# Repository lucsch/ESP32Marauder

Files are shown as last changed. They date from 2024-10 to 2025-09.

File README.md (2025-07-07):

<!---[![License: MIT](https://img.shields.io/github/license/mashape/apistatus.svg)](https://github.com/justcallmekoko/ESP32Marauder/blob/master/LICENSE)--->
<!---[![Gitter](https://badges.gitter.im/justcallmekoko/ESP32Marauder.png)](https://gitter.im/justcallmekoko/ESP32Marauder)--->
<!---[![Build Status](https://travis-ci.com/justcallmekoko/ESP32Marauder.svg?branch=master)](https://travis-ci.com/justcallmekoko/ESP32Marauder)--->
<!---Shields/Badges https://shields.io/--->

# ESP32 Marauder
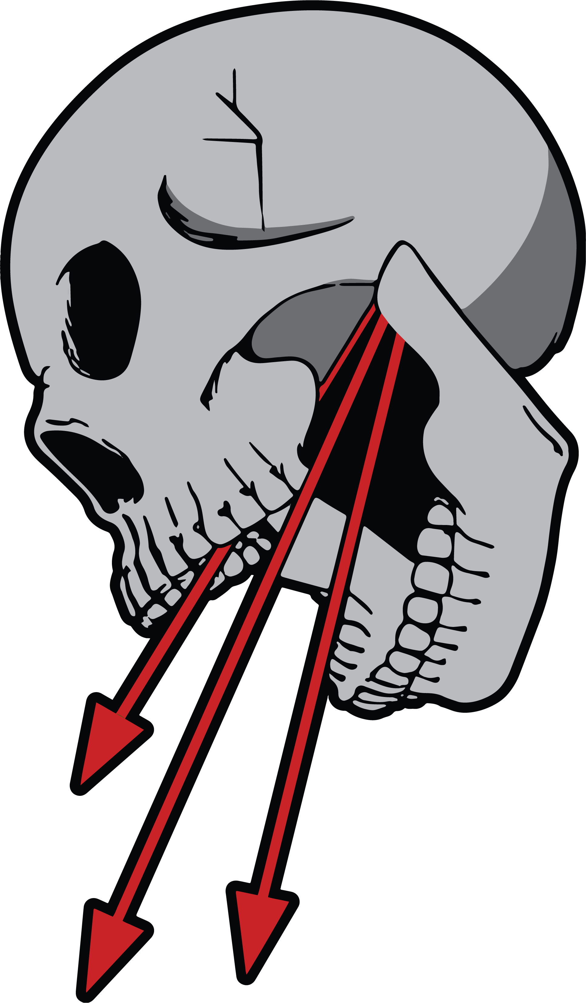
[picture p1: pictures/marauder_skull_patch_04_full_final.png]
Marauder logo

<p align="center">
  <b>A suite of WiFi/Bluetooth offensive and defensive tools for the ESP32</b>
  <br><br>
  
  
  
  <br>
  
  
  <br><br>
</p>
    


## Getting Started
Download the [latest release](https://github.com/justcallmekoko/ESP32Marauder/releases/latest) of the firmware.  

Check out the project [wiki](https://github.com/justcallmekoko/ESP32Marauder/wiki) for a full overview of the ESP32 Marauder

# For Sale Now
You can buy the ESP32 Marauder using [this link](https://www.justcallmekokollc.com)

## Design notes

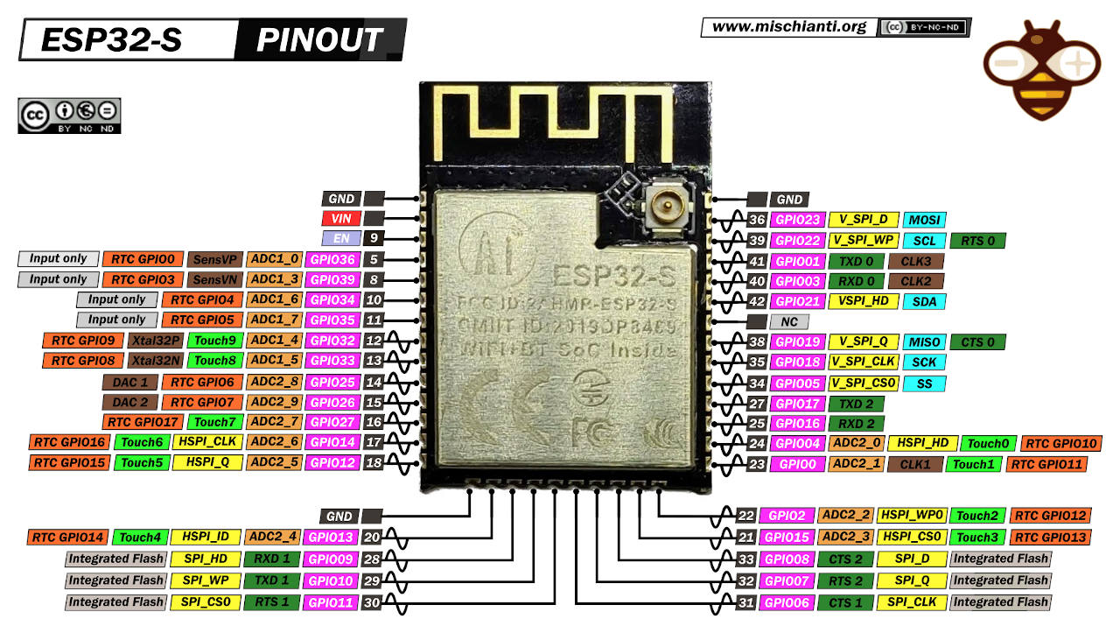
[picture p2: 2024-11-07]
schematics/esp32v6/documents/ESP32-S-pinout-mischianti-low-resolution.jpg

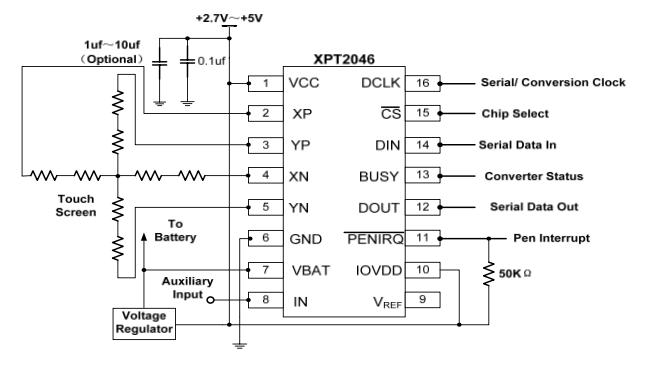
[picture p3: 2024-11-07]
schematics/esp32v6/documents/xpt2046.png

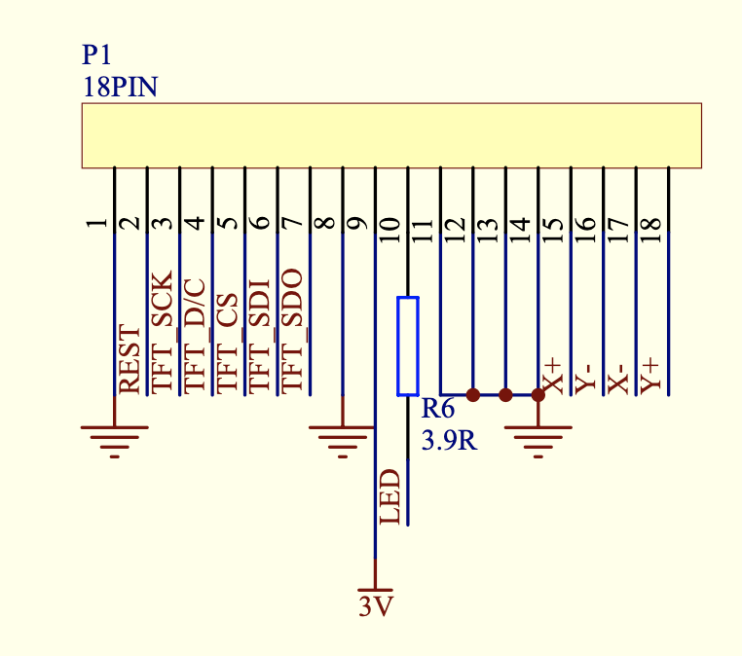
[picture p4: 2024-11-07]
schematics/esp32v6/documents/ili9341.png

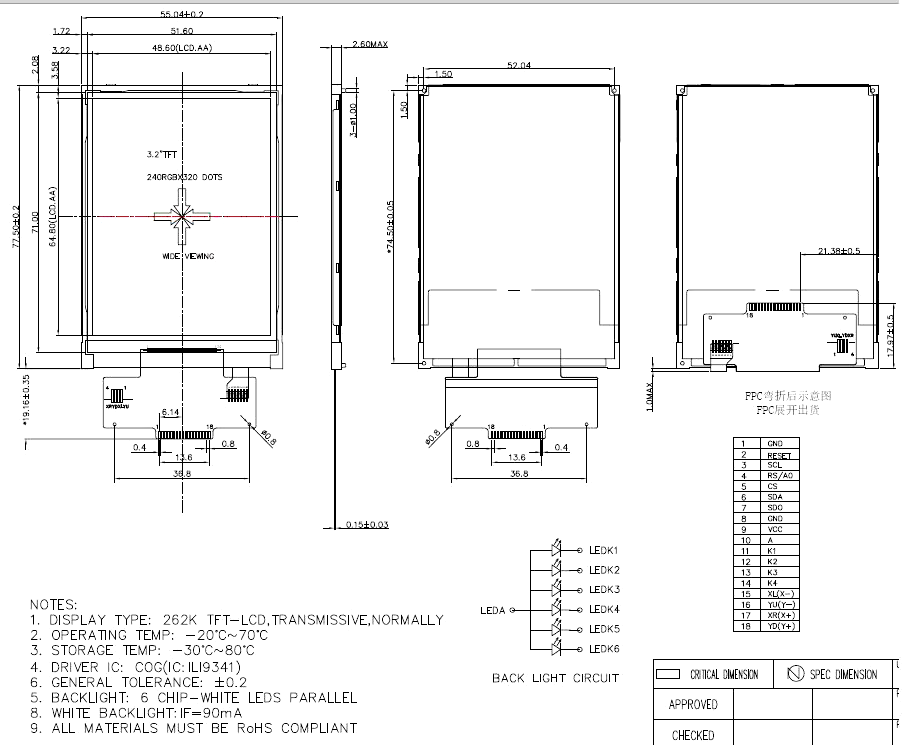
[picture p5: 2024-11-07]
schematics/esp32v6/documents/tft_display_datasheet.png

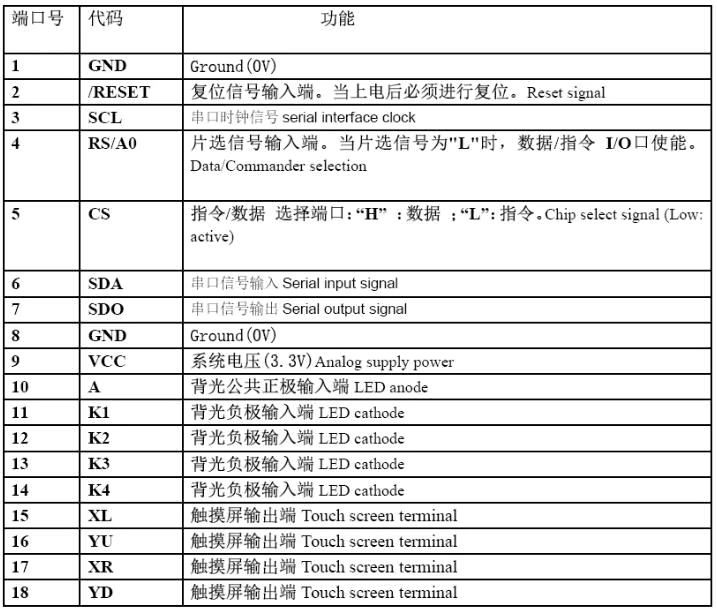
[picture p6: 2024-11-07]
schematics/esp32v6/documents/tft_display_datasheet2.png

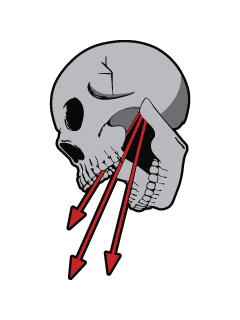
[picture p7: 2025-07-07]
pictures/marauder_skull_240x320-01-01.png

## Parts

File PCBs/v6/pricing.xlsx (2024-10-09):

null | References | Value | Footprint | Quantity | Remarque | Prix
1 | C4, C5, C6, C7, C9, C11 | 22uF | 805 | 6
2 | C1, C8, C10 | 10uF | 805 | 3
3 | C2, C3 | 100nF | 805 | 2
4 | C12 | 100nF | C0603 | 1
5 | R2, R4, R5, R6, R8, R10 | 10KΩ | 603 | 6
6 | R14, R16, R17, R18 | 1K | R0603 | 4
7 | R1, R3 | 470Ω | 805 | 2
8 | R11, R12 | 2.2K | R0603 | 2
9 | R7 | 2 | 603 | 1 |  | 0.0363
10 | R9 | 0.5 | 603 | 1 |  | 0.0398
11 | R13 | 10K | R0603 | 1
12 | R15 | 10 | R0603 | 1
13 | R19 | 330 | R0603 | 1
14 | L1 | 1uH | L-SMD-5.4X5.1 | 1 | Inductance | 0.175
15 | U1 | CH340C | SOP-16_150MIL | 1 | USB2Serial | 0.778
16 | U2 | AMS1117-3.3 | SOT-223 | 1 | LDO | 0.0188
17 | U3 | ESP-32S | ESP-32S | 1 | MCU | 1.99
18 | U5 | IP5306 | ESOP-8-EP | 1 | Power Management | 0.71
19 | U6 | XPT2046 | TSSOP-16_L5.0-W4.4-P0.65-LS6.4-BL | 1 | Contrôleur écran | 0.18
20 | U7 | ILI9341_18_PIN | ILI9341 18 PIN | 1 | Ecran | 4.79
21 | U8 | 1042P | KEYSTONE 18650 BATTERY SLED | 1 | support batterie | 0.88
22 | SW1 | POWER | KEY-TACT-SMD-7.6*3.5*3.5 | 1 | bouton latéral | 0.1016
23 | Q1, Q2 | S8050 | SOT-23(SOT-23-3) | 2 | transistor | 0.0152
24 | CARD1 | TF-115 | TF-SMD_TF-115 | 1
25 | FLASH1 | FLASH | KEY-5.2X5.2X1.5 | 1 | bouton flash | 0.0266
26 | LED1 | WS2812B-B | LED-SMD_4P-L5.0-W5.0-BL | 1
27 | Q3 | S8050_C402279 | SOT-23-3_L3.0-W1.7-P0.95-LS2.9-BR | 1 | transistor | 0.0152
28 | RESET1 | RESET | KEY-5.2X5.2X1.5 | 1 | bouton reset | 0.0266
29 | USB1 | MICROXNJ | MICRO-USB-SMD_MICROXNJ | 1
30 | P1 | Header-Female-2.54_1x16 | HDR-16X1/2.54 | 1
 |  |  |  |  | Batterie 18650 | 1.531666667
 |  |  |  |  | antenne wifi | 0.599
 |  |  |  |  | GPS | 2.43
 |  |  |  |  | PCB | 3.488

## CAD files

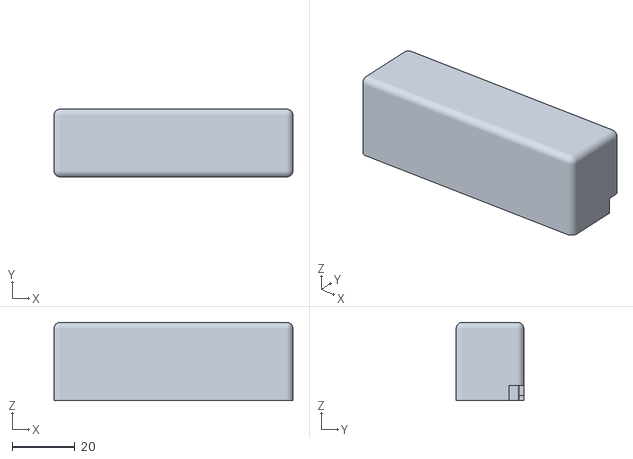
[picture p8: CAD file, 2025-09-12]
mechanical/C5 Adapter/c5 adapter pin cover.stl
76.2 x 21.6 x 25.0

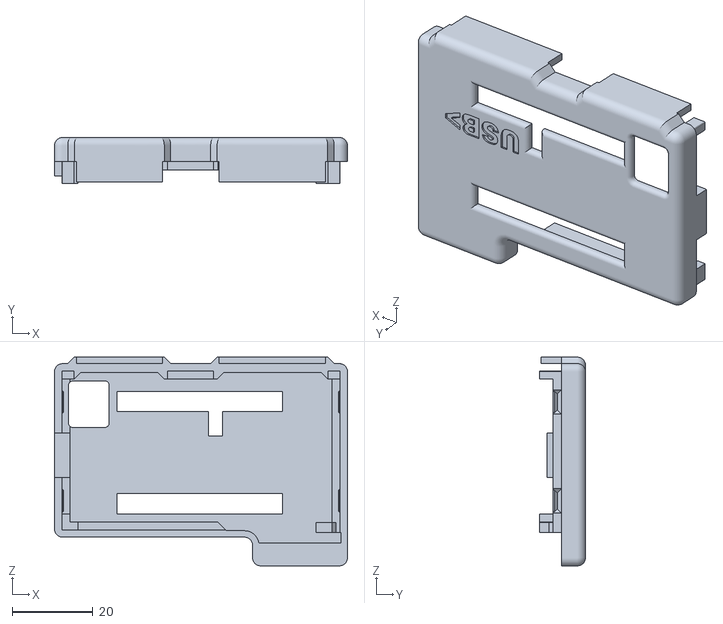
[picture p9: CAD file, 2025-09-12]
mechanical/C5 Adapter/Extra designs/c5 adapter front - SMA.stl
72.6 x 11.4 x 51.7

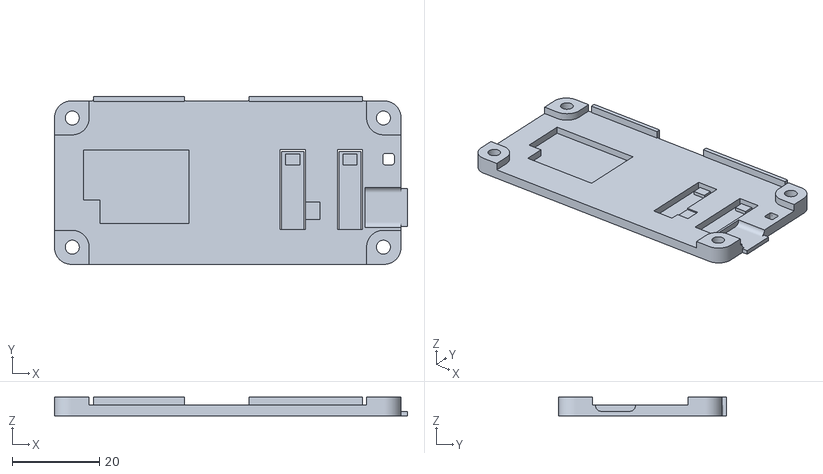
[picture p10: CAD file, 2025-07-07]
mechanical/Flipper Zero WiFi Dev Board/FlipperZero Dev Board Enclosure JCMK Lid.stl
80.7 x 38.3 x 4.30

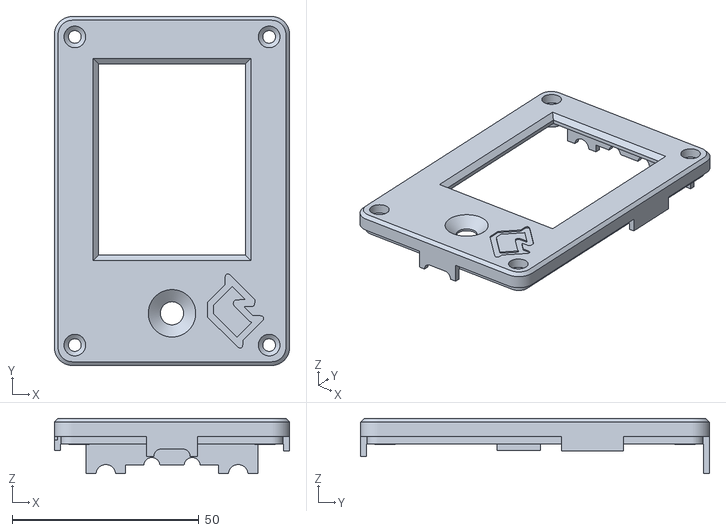
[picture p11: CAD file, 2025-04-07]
mechanical/V7/Front.stl
63.0 x 93.5 x 14.8

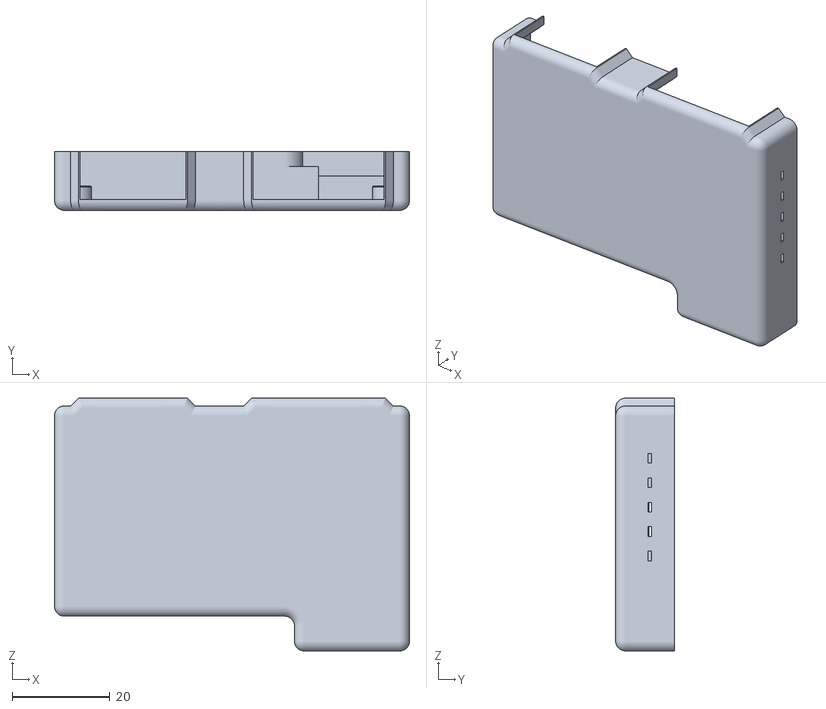
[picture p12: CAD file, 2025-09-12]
mechanical/C5 Adapter/c5 adapter back.stl
72.6 x 12.0 x 51.7

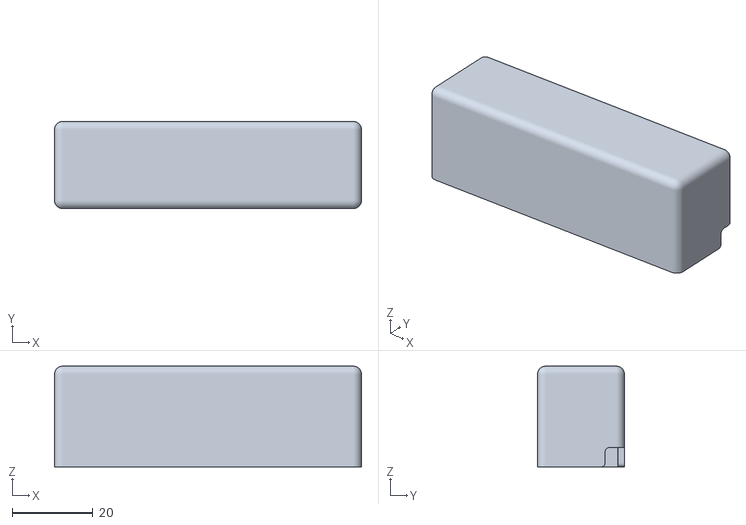
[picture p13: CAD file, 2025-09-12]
mechanical/C5 Adapter/Extra designs/c5 adapter pin cover - with cut out.stl
76.2 x 21.6 x 25.0

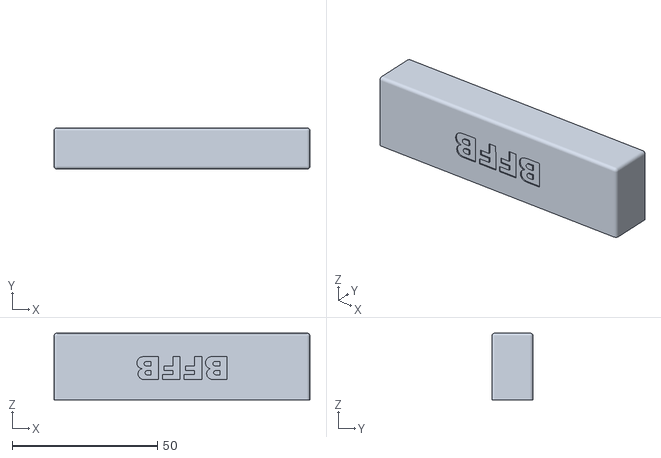
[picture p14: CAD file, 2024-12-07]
mechanical/Flipper Zero BFFB/Enclosure/GPIO Cover.stl
88.1 x 14.2 x 23.0

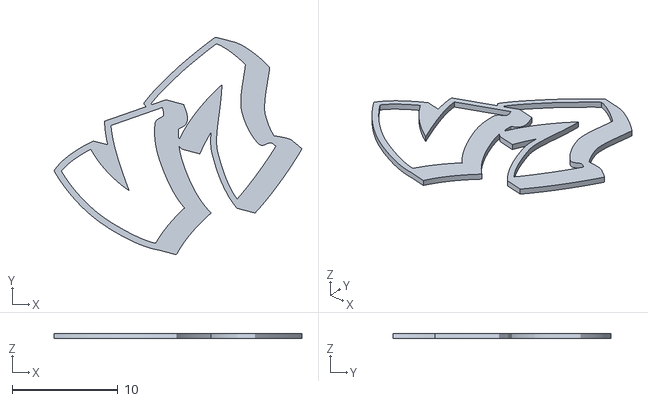
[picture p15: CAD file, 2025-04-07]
mechanical/V7/Inlay/v7 Outline.stl
23.4 x 20.6 x 0.5

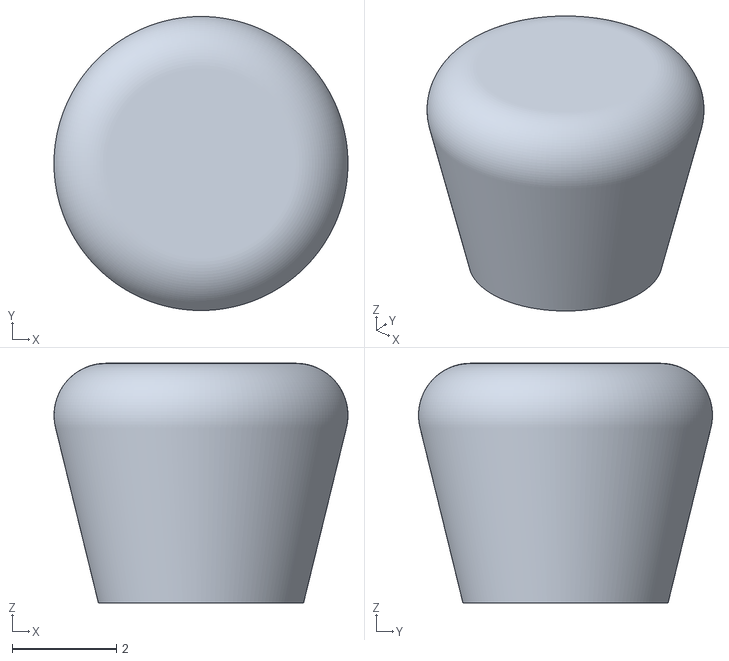
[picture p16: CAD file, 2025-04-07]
mechanical/V7/Joystick.stl
5.65 x 5.65 x 4.60

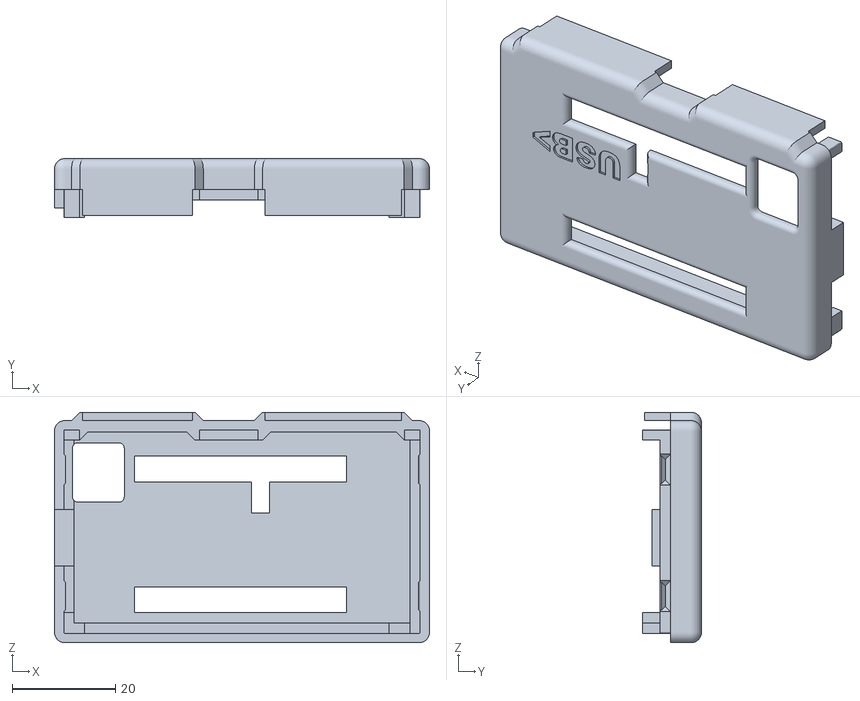
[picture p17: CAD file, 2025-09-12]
mechanical/C5 Adapter/Extra designs/c5 adapter front - logo cut out.stl
72.6 x 11.4 x 44.6

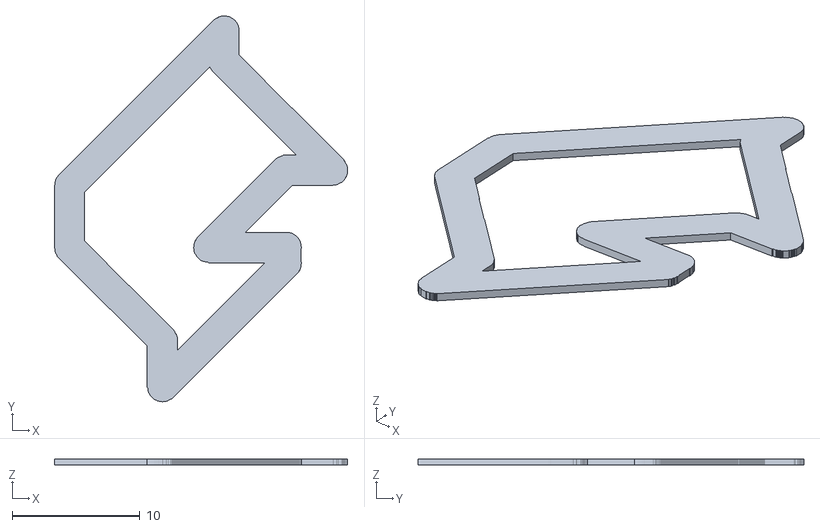
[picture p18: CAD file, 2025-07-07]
mechanical/Flipper Zero WiFi Dev Board/FlipperZero Dev Board Enclosure JCMK Inlay.stl
23.0 x 30.2 x 0.5

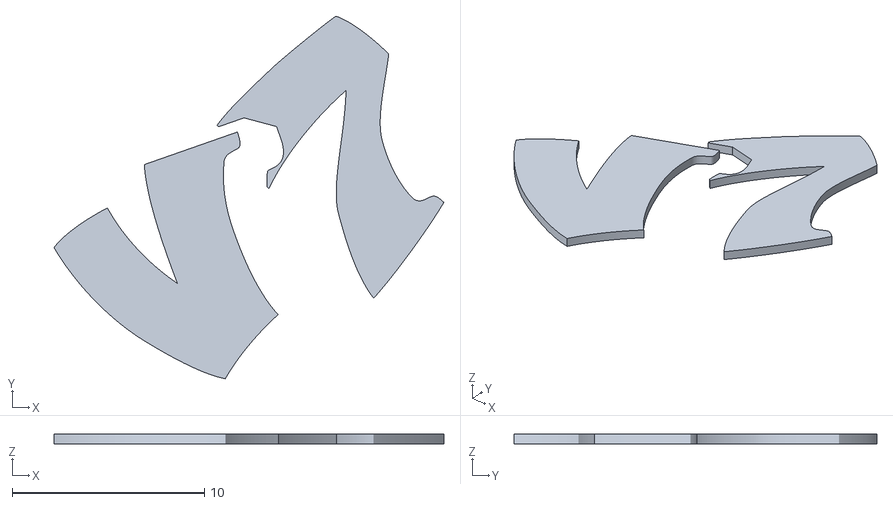
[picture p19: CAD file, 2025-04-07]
mechanical/V7/Inlay/v7 Fill.stl
20.3 x 18.8 x 0.5

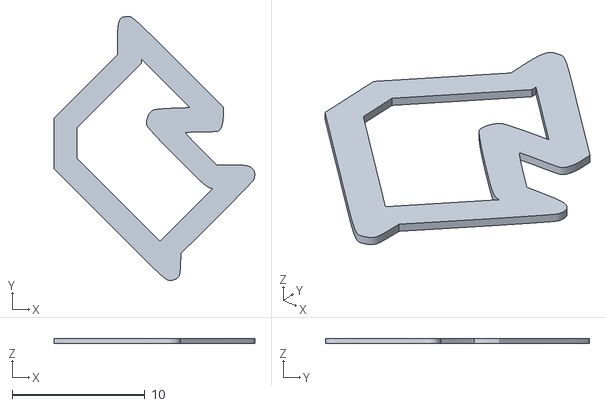
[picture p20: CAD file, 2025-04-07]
mechanical/V7/JCMK Inlay.stl
15.1 x 19.9 x 0.4

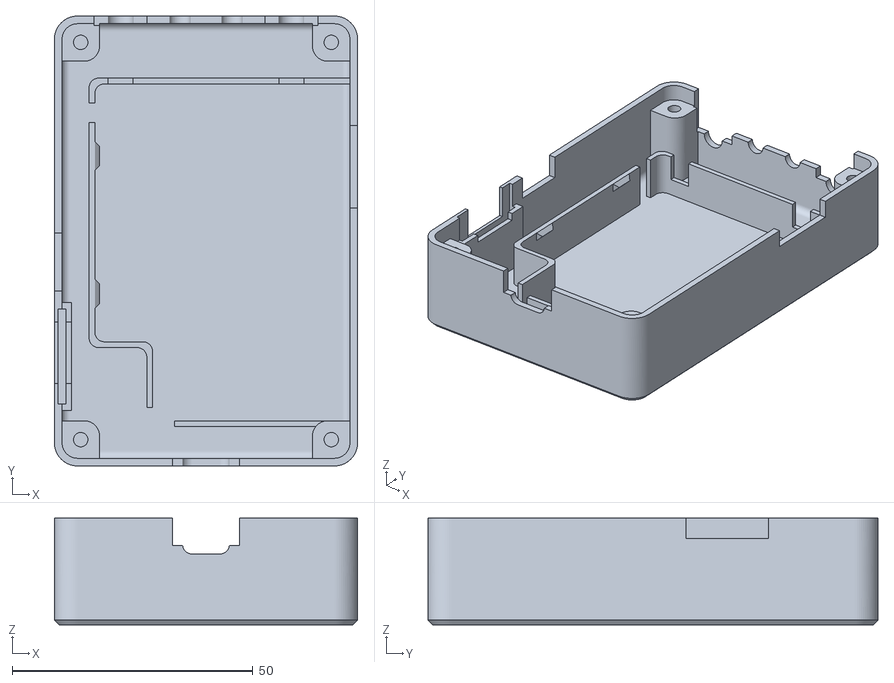
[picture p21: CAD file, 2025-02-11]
mechanical/V7/Back.stl
63.0 x 93.5 x 22.2

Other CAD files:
mechanical/V7/Inlay/Front_debos.stl
mechanical/C5 Adapter/c5 adapter front.stl
mechanical/C5 Adapter/Extra designs/c5 adapter pin cover - cut out with JCMK x AWOK logos.stl
mechanical/C5 Adapter/Extra designs/c5 adapter back - SMA.stl
mechanical/C5 Adapter/Extra designs/c5 adapter back - hatched 1.stl
mechanical/C5 Adapter/Extra designs/c5 adapter back - hatched 2.stl
mechanical/C5 Adapter/Extra designs/c5 adapter pin cover - JCMK x AWOK.stl
mechanical/Flipper Zero BFFB/Enclosure/Back.stl
mechanical/Flipper Zero BFFB/Enclosure/Front.stl
mechanical/Flipper Zero WiFi Dev Board/Wifi_Dev_REAR_THRUBOLT_STD_GPS_ANT.stl
mechanical/V6/M6_BOTTOM_LSC.FCStd
mechanical/V6/M6_BOTTOM_LSC.step
mechanical/V6/M6_BOTTOM_LSC_NO_GPS.step
mechanical/V6/MARAUDER_V6_ANTENNA_SUPPORT.step
mechanical/V6/MARAUDER_V6_TOP_LOGO_BSI.FCStd
mechanical/V6/cnc/boite_couvercle.dxf
mechanical/V6/cnc/lipo_pad.dxf
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

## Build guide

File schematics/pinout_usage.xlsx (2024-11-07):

PIN | ECRAN (ILI9341) | TACTILE (XPT2046) | SDCARD (TF-115) | PIN_HEADER | NOT_USED | MISC | Remarque
EN-RESET |  |  |  | 1
GPIO36 |  |  |  | 1
GPIO39 |  |  |  | 1
GPIO34 |  |  |  | 1
GPIO35 |  |  |  | 1
GPIO32 | Pilote Transistor |  |  |  |  |  | pilote transistor
GPIO33 |  |  |  |  |  | Mesure LED2
GPIO25 |  |  |  |  |  | Neopixel LED
GPIO26 |  |  |  |  | 1
GPIO27 |  |  |  |  | 1
GPIO14 |  |  |  | 1
GPIO12 |  |  | SPI_CS | 1
GPIO13 |  |  |  | 1
GPIO15 |  |  |  |  |  |  | Pull down uniquement
GPIO02 |  |  |  | 1
GPIO00 |  |  |  | 1 |  |  | Circuit Flash
GPIO04 |  |  |  | 1
GPIO16 | TFT_DC
GPIO17 | TFT_CS
GPIO05 | REST
GPIO18 | TFT_SCK | CLK | SPI_CLK |  |  |  | Clock
GPIO19 |  | DOUT | SPI_MISO
GPIO21 |  | CS
GPIO03 |  |  |  | 1 |  |  | RXD
GPIO01 |  |  |  | 1 |  |  | TXD
GPIO22 |  |  |  |  |  | Mesure LED1
GPIO23 | TFT_SDI-SDO | DIN | SPI_MOSI

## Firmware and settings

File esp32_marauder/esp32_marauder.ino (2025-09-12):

/* FLASH SETTINGS
Board: LOLIN D32
Flash Frequency: 80MHz
Partition Scheme: Minimal SPIFFS
https://www.online-utility.org/image/convert/to/XBM
*/

#include "configs.h"

#ifndef HAS_SCREEN
  #define MenuFunctions_h
  #define Display_h
#endif

#include <WiFi.h>
#include "EvilPortal.h"
#include <Wire.h>
#include "esp_wifi.h"
#include "esp_wifi_types.h"
#include <stdio.h>
#include "freertos/FreeRTOS.h"
#include "freertos/task.h"
#include "esp_system.h"
#include <Arduino.h>

#ifdef HAS_GPS
  #include "GpsInterface.h"
#endif

#include "Assets.h"
#include "WiFiScan.h"
#ifdef HAS_SD
  #include "SDInterface.h"
#endif
#include "Buffer.h"

#ifdef HAS_FLIPPER_LED
  #include "flipperLED.h"
#elif defined(XIAO_ESP32_S3)
  #include "xiaoLED.h"
#elif defined(MARAUDER_M5STICKC) || defined(MARAUDER_M5STICKCP2)
  #include "stickcLED.h"
#elif defined(HAS_NEOPIXEL_LED)
  #include "LedInterface.h"
#endif

#include "settings.h"
#include "CommandLine.h"
#include "lang_var.h"

#ifdef HAS_BATTERY
  #include "BatteryInterface.h"
#endif

#ifdef HAS_SCREEN
  #include "Display.h"
  #include "MenuFunctions.h"
#endif

#ifdef HAS_BUTTONS
  #include "Switches.h"
  
  #if (U_BTN >= 0)
    Switches u_btn = Switches(U_BTN, 1000, U_PULL);
  #endif
  #if (D_BTN >= 0)
    Switches d_btn = Switches(D_BTN, 1000, D_PULL);
  #endif
  #if (L_BTN >= 0)
    Switches l_btn = Switches(L_BTN, 1000, L_PULL);
  #endif
  #if (R_BTN >= 0)
    Switches r_btn = Switches(R_BTN, 1000, R_PULL);
  #endif
  #if (C_BTN >= 0)
    Switches c_btn = Switches(C_BTN, 1000, C_PULL);
  #endif

#endif

WiFiScan wifi_scan_obj;
EvilPortal evil_portal_obj;
Buffer buffer_obj;
Settings settings_obj;
CommandLine cli_obj;

#ifdef HAS_GPS
  GpsInterface gps_obj;
#endif

#ifdef HAS_BATTERY
  BatteryInterface battery_obj;
#endif

#ifdef HAS_SCREEN
  Display display_obj;
  MenuFunctions menu_function_obj;
#endif

#if defined(HAS_SD) && !defined(HAS_C5_SD)
  SDInterface sd_obj;
#endif

#ifdef MARAUDER_M5STICKC
  AXP192 axp192_obj;
#endif

#ifdef HAS_FLIPPER_LED
  flipperLED flipper_led;
#elif defined(XIAO_ESP32_S3)
  xiaoLED xiao_led;
#elif defined(MARAUDER_M5STICKC) || defined(MARAUDER_M5STICKCP2)
  stickcLED stickc_led;
#else
  LedInterface led_obj;
#endif

const String PROGMEM version_number = MARAUDER_VERSION;

#ifdef HAS_NEOPIXEL_LED
  Adafruit_NeoPixel strip = Adafruit_NeoPixel(Pixels, PIN, NEO_GRB + NEO_KHZ800);
#endif

uint32_t currentTime  = 0;

void backlightOn() {
  #ifdef HAS_SCREEN
    #ifdef MARAUDER_MINI
      digitalWrite(TFT_BL, LOW);
    #endif
  
    #ifndef MARAUDER_MINI
      digitalWrite(TFT_BL, HIGH);
    #endif
  #endif
}

void backlightOff() {
  #ifdef HAS_SCREEN
    #ifdef MARAUDER_MINI
      digitalWrite(TFT_BL, HIGH);
    #endif
  
    #ifndef MARAUDER_MINI
      digitalWrite(TFT_BL, LOW);
    #endif
  #endif
}

#ifdef HAS_C5_SD
  SPIClass sharedSPI(SPI);
  SDInterface sd_obj = SDInterface(&sharedSPI, SD_CS);
#endif

void setup()
{
  #ifndef HAS_DUAL_BAND
    esp_spiram_init();
  #endif

  #ifdef HAS_C5_SD
    Serial.println("Starting shared SPI for C5 SD configuration...");
    sharedSPI.begin(SD_SCK, SD_MISO, SD_MOSI);
    delay(100);
  #endif

  #ifdef defined(MARAUDER_M5STICKC) && !defined(MARAUDER_M5STICKCP2)
    axp192_obj.begin();
  #endif

  #if defined(MARAUDER_M5STICKCP2) // Prevent StickCP2 from turning off when disconnect USB cable
    pinMode(POWER_HOLD_PIN, OUTPUT);
    digitalWrite(POWER_HOLD_PIN, HIGH);
  #endif
  
  #ifdef HAS_SCREEN
    pinMode(TFT_BL, OUTPUT);
  #endif
  
  backlightOff();
  #if BATTERY_ANALOG_ON == 1
    pinMode(BATTERY_PIN, OUTPUT);
    pinMode(CHARGING_PIN, INPUT);
  #endif
  
  // Preset SPI CS pins to avoid bus conflicts
  #ifdef HAS_SCREEN
    digitalWrite(TFT_CS, HIGH);
  #endif
  
  #if defined(HAS_SD) && !defined(HAS_C5_SD)
    pinMode(SD_CS, OUTPUT);

    delay(10);
  
    digitalWrite(SD_CS, HIGH);

    delay(10);
  #endif

  Serial.begin(115200);

  while(!Serial)
    delay(10);

  Serial.println("ESP-IDF version is: " + String(esp_get_idf_version()));

  #ifdef HAS_PSRAM
    if (psramInit()) {
      Serial.println("PSRAM is correctly initialized");
    } else {
      Serial.println("PSRAM not available");
    }
  #endif

  #ifdef HAS_SCREEN
    display_obj.RunSetup();
    display_obj.tft.setTextColor(TFT_WHITE, TFT_BLACK);
  #endif

  backlightOff();

  #ifdef HAS_SCREEN
    #ifndef MARAUDER_CARDPUTER
      display_obj.tft.drawCentreString("ESP32 Marauder", TFT_WIDTH/2, TFT_HEIGHT * 0.33, 1);
      display_obj.tft.drawCentreString("JustCallMeKoko", TFT_WIDTH/2, TFT_HEIGHT * 0.5, 1);
      display_obj.tft.drawCentreString(display_obj.version_number, TFT_WIDTH/2, TFT_HEIGHT * 0.66, 1);
    #else
      display_obj.tft.drawCentreString("ESP32 Marauder", TFT_HEIGHT/2, TFT_WIDTH * 0.33, 1);
      display_obj.tft.drawCentreString("JustCallMeKoko", TFT_HEIGHT/2, TFT_WIDTH * 0.5, 1);
      display_obj.tft.drawCentreString(display_obj.version_number, TFT_HEIGHT/2, TFT_WIDTH * 0.66, 1);
    #endif
  #endif


  backlightOn(); // Need this

  #ifdef HAS_SCREEN
    //delay(2000);

    // Do some stealth mode stuff
    #ifdef HAS_BUTTONS
      if (c_btn.justPressed()) {
        display_obj.headless_mode = true;

        backlightOff();

        Serial.println("Headless Mode enabled");
      }
    #endif

    //display_obj.clearScreen();
  
    //display_obj.tft.setTextColor(TFT_CYAN, TFT_BLACK);
  
    //display_obj.tft.println(text_table0[0]);
  
    //delay(2000);
  
    //display_obj.tft.println("Marauder " + display_obj.version_number + "\n");
  
    //display_obj.tft.println(text_table0[1]);
  #endif

  settings_obj.begin();

  buffer_obj = Buffer();
  #if defined(HAS_SD)
    // Do some SD stuff
    if(!sd_obj.initSD())
      Serial.println(F("SD Card NOT Supported"));

  #endif

  wifi_scan_obj.RunSetup();

  #ifdef HAS_SCREEN
    display_obj.tft.setTextColor(TFT_GREEN, TFT_BLACK);
    display_obj.tft.drawCentreString("Initializing...", TFT_WIDTH/2, TFT_HEIGHT * 0.82, 1);
  #endif

  evil_portal_obj.setup();

  #ifdef HAS_BATTERY
    battery_obj.RunSetup();
  #endif

  #ifdef HAS_BATTERY
    battery_obj.battery_level = battery_obj.getBatteryLevel();
  #endif

  // Do some LED stuff
  #ifdef HAS_FLIPPER_LED
    flipper_led.RunSetup();
  #elif defined(XIAO_ESP32_S3)
    xiao_led.RunSetup();
  #elif defined(MARAUDER_M5STICKC)
    stickc_led.RunSetup();
  #else
    led_obj.RunSetup();
  #endif

  #ifdef HAS_GPS
    gps_obj.begin();
  #endif

  #ifdef HAS_SCREEN  
    display_obj.tft.setTextColor(TFT_WHITE, TFT_BLACK);
  #endif

  #ifdef HAS_SCREEN
    menu_function_obj.RunSetup();
  #endif

  wifi_scan_obj.StartScan(WIFI_SCAN_OFF);
  
  Serial.println(F("CLI Ready"));
  cli_obj.RunSetup();
}


void loop()
{
  currentTime = millis();
  bool mini = false;

  #ifdef SCREEN_BUFFER
    #ifndef HAS_ILI9341
      mini = true;
    #endif
  #endif

  #if (defined(HAS_ILI9341) && !defined(MARAUDER_CYD_2USB))
    #ifdef HAS_BUTTONS
      if (c_btn.isHeld()) {
        if (menu_function_obj.disable_touch)
          menu_function_obj.disable_touch = false;
        else
          menu_function_obj.disable_touch = true;

        menu_function_obj.updateStatusBar();

        while (!c_btn.justReleased())
          delay(1);
      }
    #endif
  #endif

  // Update all of our objects
  cli_obj.main(currentTime);
  #ifdef HAS_SCREEN
    display_obj.main(wifi_scan_obj.currentScanMode);
  #endif
  wifi_scan_obj.main(currentTime);

  #ifdef HAS_GPS
    gps_obj.main();
  #endif
  
  // Detect SD card
  #if defined(HAS_SD)
    sd_obj.main();
  #endif

  // Save buffer to SD and/or serial
  buffer_obj.save();

  #ifdef HAS_BATTERY
    battery_obj.main(currentTime);
  #endif
  settings_obj.main(currentTime);
  if (((wifi_scan_obj.currentScanMode != WIFI_PACKET_MONITOR) && (wifi_scan_obj.currentScanMode != WIFI_SCAN_EAPOL)) ||
      (mini)) {
    #ifdef HAS_SCREEN
      menu_function_obj.main(currentTime);
    #endif
  }
  #ifdef HAS_FLIPPER_LED
    flipper_led.main();
  #elif defined(XIAO_ESP32_S3)
    xiao_led.main();
  #elif defined(MARAUDER_M5STICKC)
    stickc_led.main();
  #else
    led_obj.main(currentTime);
  #endif

  #ifdef HAS_SCREEN
    delay(1);
  #else
    delay(50);
  #endif
}

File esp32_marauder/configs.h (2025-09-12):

#pragma once

#ifndef configs_h

  #define configs_h

  #define POLISH_POTATO

  //// BOARD TARGETS
  //#define MARAUDER_M5STICKC
  //#define MARAUDER_M5STICKCP2
  //#define MARAUDER_MINI
  //#define MARAUDER_V4
  //#define MARAUDER_V6
  //#define MARAUDER_V6_1
  //#define MARAUDER_V7
  //#define MARAUDER_V7_1
  //#define MARAUDER_KIT
  //#define GENERIC_ESP32
  //#define MARAUDER_FLIPPER
  //#define MARAUDER_MULTIBOARD_S3
  //#define ESP32_LDDB
  //#define MARAUDER_DEV_BOARD_PRO
  //#define XIAO_ESP32_S3
  //#define MARAUDER_REV_FEATHER
  //#define MARAUDER_CYD_MICRO // 2432S028
  //#define MARAUDER_CYD_2USB // Another 2432S028 but it has tWo UsBs OoOoOoO
  //#define MARAUDER_CYD_GUITION // ESP32-2432S024 GUITION
  //#define MARAUDER_C5
  //#define MARAUDER_CARDPUTER
  //// END BOARD TARGETS

  #define MARAUDER_VERSION "v1.8.5"

  #define GRAPH_REFRESH   100

  #define DUAL_BAND_CHANNELS 51

  //// HARDWARE NAMES
  #ifdef MARAUDER_M5STICKC
    #define HARDWARE_NAME "M5Stick-C Plus"
  #elif defined(MARAUDER_M5STICKCP2)
    #define HARDWARE_NAME "M5Stick-C Plus2"
  #elif defined(MARAUDER_CARDPUTER)
    #define HARDWARE_NAME "M5 Cardputer"
  #elif defined(MARAUDER_MINI)
    #define HARDWARE_NAME "Marauder Mini"
  #elif defined(MARAUDER_V7)
    #define HARDWARE_NAME "Marauder v7"
  #elif defined(MARAUDER_V7_1)
    #define HARDWARE_NAME "Marauder v7.1"
  #elif defined(MARAUDER_REV_FEATHER)
    #define HARDWARE_NAME "Adafruit Feather ESP32-S2 Reverse TFT"
  #elif defined(MARAUDER_V4)
    #define HARDWARE_NAME "Marauder v4"
  #elif defined(MARAUDER_V6)
    #define HARDWARE_NAME "Marauder v6"
  #elif defined(MARAUDER_V6_1)
    #define HARDWARE_NAME "Marauder v6.1"
  #elif defined(MARAUDER_CYD_MICRO)
    #define HARDWARE_NAME "CYD 2432S028"
  #elif defined(MARAUDER_CYD_2USB)
    #define HARDWARE_NAME "CYD 2432S028 2USB"  
  #elif defined(MARAUDER_CYD_GUITION)
    #define HARDWARE_NAME "CYD 2432S024 GUITION"
  #elif defined(MARAUDER_KIT)
    #define HARDWARE_NAME "Marauder Kit"
  #elif defined(MARAUDER_FLIPPER)
    #define HARDWARE_NAME "Flipper Zero Dev Board"
  #elif defined(MARAUDER_MULTIBOARD_S3)
    #define HARDWARE_NAME "Flipper Zero Multi Board S3"
  #elif defined(ESP32_LDDB)
    #define HARDWARE_NAME "ESP32 LDDB"
  #elif defined(MARAUDER_DEV_BOARD_PRO)
    #define HARDWARE_NAME "Flipper Zero Dev Board Pro"
  #elif defined(XIAO_ESP32_S3)
    #define HARDWARE_NAME "XIAO ESP32 S3"
  #elif defined(MARAUDER_C5)
    #define HARDWARE_NAME "ESP32-C5 DevKit"
  #else
    #define HARDWARE_NAME "ESP32"
  #endif

  //// END HARDWARE NAMES

 //// BOARD FEATURES
  #if defined(MARAUDER_M5STICKC) || defined(MARAUDER_M5STICKCP2)
    //#define FLIPPER_ZERO_HAT
    #define HAS_MINI_KB
    #define HAS_BATTERY
    #define HAS_BT
    #define HAS_BUTTONS
    //#define HAS_NEOPIXEL_LED
    #define HAS_PWR_MGMT
    #define HAS_SCREEN
    #define HAS_MINI_SCREEN
    #define HAS_SD
    #define USE_SD
    #define HAS_TEMP_SENSOR
    #define HAS_GPS
  #endif

  #if defined(MARAUDER_CARDPUTER)
    //#define FLIPPER_ZERO_HAT
    #define HAS_MINI_KB
    //#define HAS_BATTERY
    #define HAS_BT
    #define HAS_BUTTONS
    //#define HAS_NEOPIXEL_LED
    //#define HAS_PWR_MGMT
    #define HAS_SCREEN
    #define HAS_MINI_SCREEN
    #define HAS_SD
    #define USE_SD
    #define HAS_TEMP_SENSOR
    #define HAS_GPS
  #endif

  #ifdef MARAUDER_MINI
    //#define FLIPPER_ZERO_HAT
    //#define HAS_BATTERY
    #define HAS_MINI_KB
    #define HAS_BT
    #define HAS_BUTTONS
    #define HAS_NEOPIXEL_LED
    //#define HAS_PWR_MGMT
    #define HAS_SCREEN
    #define HAS_MINI_SCREEN
    #define HAS_SD
    #define USE_SD
    #define HAS_TEMP_SENSOR
    #define HAS_GPS
  #endif

  #ifdef MARAUDER_V7
    //#define FLIPPER_ZERO_HAT
    #define HAS_MINI_KB
    #define HAS_BATTERY
    #define HAS_BT
    #define HAS_BT_REMOTE
    #define HAS_BUTTONS
    #define HAS_NEOPIXEL_LED
    //#define HAS_PWR_MGMT
    #define HAS_SCREEN
    #define HAS_FULL_SCREEN
    #define HAS_SD
    #define USE_SD
    #define HAS_TEMP_SENSOR
    #define HAS_GPS
  #endif

  #ifdef MARAUDER_V7_1
    //#define FLIPPER_ZERO_HAT
    #define HAS_MINI_KB
    #define HAS_BATTERY
    #define HAS_BT
    #define HAS_BT_REMOTE
    #define HAS_BUTTONS
    #define HAS_NEOPIXEL_LED
    //#define HAS_PWR_MGMT
    #define HAS_SCREEN
    #define HAS_FULL_SCREEN
    #define HAS_SD
    #define USE_SD
    #define HAS_TEMP_SENSOR
    #define HAS_GPS
    #define HAS_PSRAM
  #endif

  #ifdef MARAUDER_REV_FEATHER
    //#define FLIPPER_ZERO_HAT
    //#define HAS_BATTERY
    //#define HAS_BT
    #define HAS_MINI_KB
    #define HAS_BUTTONS
    #define HAS_NEOPIXEL_LED
    //#define HAS_PWR_MGMT
    #define HAS_SCREEN
    #define HAS_MINI_SCREEN
    #define HAS_SD
    #define USE_SD
    #define HAS_TEMP_SENSOR
    #define HAS_GPS
  #endif
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

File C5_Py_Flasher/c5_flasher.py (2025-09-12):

# === ESP32-C5 Auto Flasher Script By: AWOK ===

import sys
import subprocess
import os
import platform   # Placeholder for possible OS checks
import glob
import time
import shutil
import argparse

def ensure_package(pkg):
    try:
        __import__(pkg if pkg != 'gitpython' else 'git')
    except ImportError:
        print(f"Installing missing package: {pkg}")
        subprocess.check_call([sys.executable, '-m', 'pip', 'install', '--upgrade', pkg])

try:
    import serial.tools.list_ports
except ImportError:
    ensure_package('pyserial')
try:
    import esptool
except ImportError:
    ensure_package('esptool')
try:
    from colorama import Fore, Style
except ImportError:
    ensure_package('colorama')

# Dependency check and install if needed
REQUIRED_PACKAGES = [
    'pyserial',
    'esptool',
    'colorama'
]

def ensure_requirements():
    for pkg in REQUIRED_PACKAGES:
        ensure_package(pkg)
ensure_requirements()

# Finds the first file from a list of possible names in the bins folder
def find_file(name_options, bins_dir):
    for name in name_options:
        files = glob.glob(os.path.join(bins_dir, name))
        if files:
            return files[0]
    return None

def main():
    parser = argparse.ArgumentParser(description="ESP32-C5 Auto Flasher (bins subdir)")
    parser.parse_args()

    bins_dir = os.path.join(os.path.dirname(__file__), 'bins')
    if not os.path.isdir(bins_dir):
        print(Fore.RED + f"Bins directory not found: {bins_dir}\nPlease create a 'bins' folder with your .bin files." + Style.RESET_ALL)
        exit(1)

    # Logo and splash, both centered and purple
    terminal_width = shutil.get_terminal_size((100, 20)).columns
    def center(text): return text.center(terminal_width)
    logo_lines = [
        "                                            @@@@@@                              ",
        "                                @@@@@@@@  @@@@@ @@@@                            ",
        "                               @@@    @@@@@@@     @@@     @@@@@@@@              ",
        "                    @@@@@@@@@@@@@      @@@@@       @@@  @@@@    @@@             ",
        "                   @@@      @@@@@       @@@         @@@@@@       @@@            ",
        "                  @@@         @@@        @@         @@@@         @@@            ",
        "         @@@@@@@@@@@@          @@        @          @@@         @@@     @@      ",
        "        @@@     @@@@@           @@           @@@    @@          @@@@@@@@@@@@@@  ",
        "       @@@         @@@           @@          @@@               @@@@@        @@@@",
        "       @@@           @@                     @@@@              @@@            @@@",
        "      @@@@@            @@                   @@@@                             @@@",
        "   @@@@@@  @@                @@         @   @@@                            @@@@ ",
        "  @@@                         @@       @@         @                     @@@@@@  ",
        " @@@                           @@     @@@        @@            @@@@@@@@@@@@@@@  ",
        "@@@       @@@@      @          @@@@  @@@@@     @@@        @      @@@@  @@@ @@@  ",
        "@@@       @@@@@@@    @@@       @@@@@@@@@@@@@@@@@@@       @@        @@@ @@@      ",
        "@@@        @@@@@ @@@  @@@@@  @@@@ @@@@  @@@@@@@@@@      @@@@        @@@         ",
        "@@@@            @@@@@@@@@@@@@@@@  @@@   @@@ @@  @@@@@@@@@@@@         @@@        ",
        " @@@@          @@@@@@@@@@@@@@@@   @@@       @@   @@@@@@@@@@@@        @@@        ",
        "  @@@@@@     @@@@@   @@@     @@    @               @@  @@  @@@@    @@@@         ",
        "   @@@@@@@@@@@@@     @@@     @@                    @@  @@   @@@@@@@@@@@         ",
        "   @@@@@@@@@@@@      @@@     @@                   @@@  @     @@@@@@@@           ",
        "        @@  @@                                    @@@        @@  @@@            ",
        "        @   @@                                               @@  @@@            ",
        "           @@@                                                   @@@            ",
        "           @@@                                                                  ",
        ""
    ]
    splash_lines = [
        "--  ESP32 C5 Flasher --",
        "By AWOK",
        "Inspired from LordSkeletonMans ESP32 FZEasyFlasher",
        "Shout out to JCMK for the inspiration on setting up the C5",
        ""
    ]
    print(Fore.MAGENTA + "\n" + "\n".join(center(line) for line in logo_lines + splash_lines) + Style.RESET_ALL)

    # Wait for ESP32 device to show up as a new serial port
    existing_ports = set([port.device for port in serial.tools.list_ports.comports()])
    print(Fore.YELLOW + "Waiting for ESP32-C5 device to be connected..." + Style.RESET_ALL)
    while True:
        current_ports = set([port.device for port in serial.tools.list_ports.comports()])
        new_ports = current_ports - existing_ports
        if new_ports:
            serial_port = new_ports.pop()
            break
        time.sleep(0.5)
    print(Fore.GREEN + f"Detected ESP32-C5 on port: {serial_port}" + Style.RESET_ALL)

    # Find bin files for each firmware component
    bootloader = find_file(['bootloader.bin'], bins_dir)
    partitions = find_file(['partition-table.bin', 'partitions.bin'], bins_dir)
    ota_data = find_file(['ota_data_initial.bin'], bins_dir)

    # Main firmware: largest bin in the folder that's not bootloader, partition, or OTA
    all_bins = glob.glob(os.path.join(bins_dir, "*.bin"))
    exclude = {bootloader, partitions, ota_data}
    firmware_bins = [f for f in all_bins if f not in exclude and os.path.isfile(f)]
    if not firmware_bins:
        print(Fore.RED + "No application firmware .bin file found in the 'bins' folder!" + Style.RESET_ALL)
        exit(1)
    app_bin = max(firmware_bins, key=lambda f: os.path.getsize(f))

    # Print summary, ask for confirmation before flashing
    print(Fore.CYAN + f"\nBootloader:   {bootloader or 'NOT FOUND'}")
    print(f"Partitions:   {partitions or 'NOT FOUND'}")
    print(f"OTA Data:     {ota_data or 'NOT FOUND'}")
    print(f"App (main):   {app_bin}\n" + Style.RESET_ALL)
    if not (bootloader and partitions):
        print(Fore.RED + "Missing bootloader or partition table. Both are required for a complete flash!" + Style.RESET_ALL)
        exit(1)
    confirm = input(Fore.YELLOW + "Ready to flash these files to ESP32-C5? (y/N): " + Style.RESET_ALL)
    if confirm.strip().lower() != 'y':
        print("Aborting.")
        exit(0)

    # Flash using esptool, with offsets for C5
    esptool_args = [
        '--chip', 'esp32c5',
        '--port', serial_port,
        '--baud', '921600',
        '--before', 'default_reset',
        '--after', 'hard_reset',
        'write_flash', '-z',
        '0x2000', bootloader,
        '0x8000', partitions,
    ]
    if ota_data:
        esptool_args += ['0xd000', ota_data]
    esptool_args += ['0x10000', app_bin]
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

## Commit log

2024-10-09 Adding interactive BOM
2024-10-09 Adding total pricing
    [pricing.xlsx]
2024-10-13 Updating 3D enclosure
    [M6_BOTTOM_LSC.FCStd]
2024-10-13 Adding step file for enclosure
    [M6_BOTTOM_LSC.step]
2024-10-14 Trying esp32 marauder with platformio
2024-10-28 Adding schematic for CH340C testing
    [ch340_test.kicad_pcb, ch340_test.kicad_sch]
2024-11-03 Adding code for testing RGB led
2024-11-07 Adding reverse engineering for esp32
    [esp32v6.kicad_pcb, esp32v6.kicad_sch]
2024-11-07 Reverse schematic for ESP32 done
    [esp32v6.kicad_sch]
2024-11-07 Testing SDCard
    [pinout_usage.xlsx]
2024-11-07 Adding test code for CYD
    [pinout_usage.xlsx]
2024-11-08 Updating schematic
    [esp32v6.kicad_sch]
2024-11-10 Adding same code for touch test on Marauder and CYD board
2024-12-07 Adding 3D front cover
    [MARAUDER_V6_TOP_LOGO_BSI.FCStd]
2024-12-07 Adding 3D back without hole for GPS
    [M6_BOTTOM_LSC.FCStd, M6_BOTTOM_LSC_NO_GPS.step]
2024-12-16 Updating 3D files
    [M6_BOTTOM_LSC.FCStd, M6_BOTTOM_LSC.step, MARAUDER_V6_ANTENNA_SUPPORT.step]
2024-12-22 Updating 3D bottom design
    [M6_BOTTOM_LSC.FCStd, M6_BOTTOM_LSC.step]
2025-02-04 Updating 3D front design
    [MARAUDER_V6_TOP_LOGO_BSI.FCStd]
2025-02-19 Updating 3D font design (Juan)
    [MARAUDER_V6_TOP_LOGO_BSI.FCStd]
2025-09-13 Adding milling CNC files
    [boite_bas_v2.step, boite_couvercle.dxf, couvercle_gps_v2.step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]
